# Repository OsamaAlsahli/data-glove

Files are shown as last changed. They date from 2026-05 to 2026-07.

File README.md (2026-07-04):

# Data Glove

Low-cost, high-accuracy data glove with real-time hand motion tracking and
fingertip force sensing.

Final Year Project — **Osama Alsahli**, BEng Electronic Engineering, University
of York, 2026.

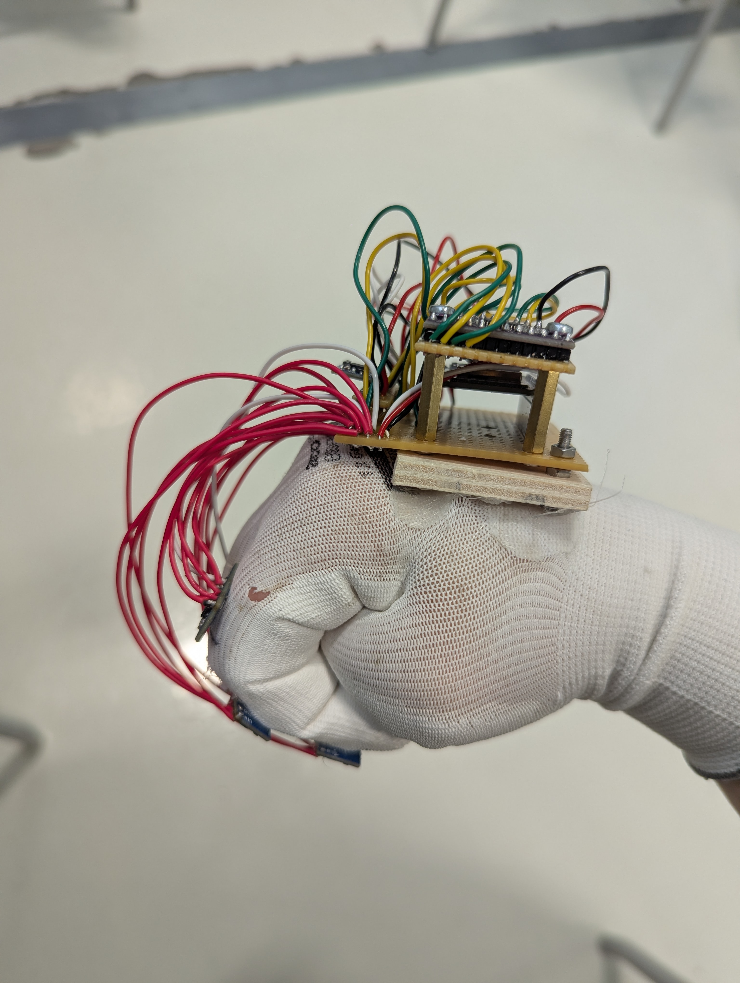
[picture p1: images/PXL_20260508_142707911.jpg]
Data glove prototype with fingertip STOF sensor and IMU wiring


## What this is

A wearable glove that captures finger and hand orientation using sixteen
BNO055 9-axis IMUs (one per finger phalanx plus one on the dorsum), with
soft optical tactile sensors (STOF) at the fingertips for contact force.
Quaternion data is streamed from an ESP32 over USB serial to a Python
bridge, which serves it to the FSGlove visualisation framework via gRPC.

Headline hardware bill of materials: 16× BNO055 IMUs, 2× TCA9548A I2C
multiplexers, one ESP32 dev board, soft Ecoflex 00-30 STOF sensors at the
fingertips. Total cost of purchased electronics ≈ £105.

For the full report (motivation, lit review, design, evaluation), see the
accompanying BEng final report.

## Repository layout

```
firmware/         ESP32 Arduino sketches (C++)
  adafruit_test/  Single-BNO055 smoke test
  tst/            Single sensor through TCA9548A
  tst2/           TCA9548A I2C scanner
  webserial_3d/   Single sensor for the Adafruit WebSerial 3D viewer
  quat_finger/    4-IMU single-finger demo
  quat/           Full 16-IMU glove firmware
  fsglove-main/   FSGlove visualisation framework (third-party, included
                  for reproducibility - see Licence section)

bridge/           Python serial-to-gRPC bridge
  bridge.py            Full 16-sensor bridge (the one you actually run)
  bridge_finger.py     Incomplete 4-sensor variant, kept for reference
  read_imu.py          Minimal serial quaternion printer
  visualise_imu.py     Live OpenGL "bone" visualiser

images/           Prototype photos, kinematic model, Gantt chart
schematics/       PCB / schematic designs (KiCad) for STOF and main board
```

## How to flash the firmware

1. Open `firmware/quat/quat.ino` in the Arduino IDE.
2. Install the **Adafruit BNO055** and **Adafruit Unified Sensor** libraries
   from the Library Manager.
3. Select the ESP32 board, the matching USB serial port, and upload.

The single-sensor bring-up sketches (`adafruit_test`, `tst`, `tst2`,
`webserial_3d`) are useful for verifying hardware before flashing the full
build.

## How to run the bridge

```bash
cd bridge
pip install pyserial grpcio
# Generate imu_packet_pb2.py / imu_packet_pb2_grpc.py from the FSGlove proto
# (imu_packet.proto lives inside firmware/fsglove-main).
python bridge.py
```

The bridge listens on `localhost:18890`; start FSGlove afterwards and it
will subscribe to the stream.

If you want to drive the visualiser without hardware, swap the
`target=read_serial` line in `bridge.py`'s `main()` for
`target=generate_fake_serial`.

## Licence

The code I wrote (everything under `firmware/` except `fsglove-main/`, and
everything under `bridge/`) is released for academic and personal use.

`firmware/fsglove-main/` is included for reproducibility only and is the
work of its original authors — see its own README and licence inside that
folder or (<https://github.com/davidliyutong/fsglove>). The SMPLH model weights (`SMPLH_male.pkl`, `SMPLH_female.pkl`)
required by FSGlove are **not** included in this repo. To obtain them and
get FSGlove running, follow the setup instructions in the upstream FSGlove
repository (<https://github.com/davidliyutong/fsglove>); the project page
is at <https://sites.google.com/view/fsglove/>.

## Known limitations

- **Single multiplexer firmware.** `firmware/quat/quat.ino` was written
  assuming one 16 channel multiplexer, but the final hardware splits the
  16 IMUs across two TCA9548As (each with 8 channels). Reading sensors 8 to 15
  therefore needs a second multiplexer select layer that this build does
  not yet implement. The limitation is flagged inline with a `NOTE:` comment.
  The single finger and 8 sensor paths are fully working.
- `bridge/bridge_finger.py` is an unfinished early version of the bridge,
  kept for historical reference. The working bridge is `bridge/bridge.py`.

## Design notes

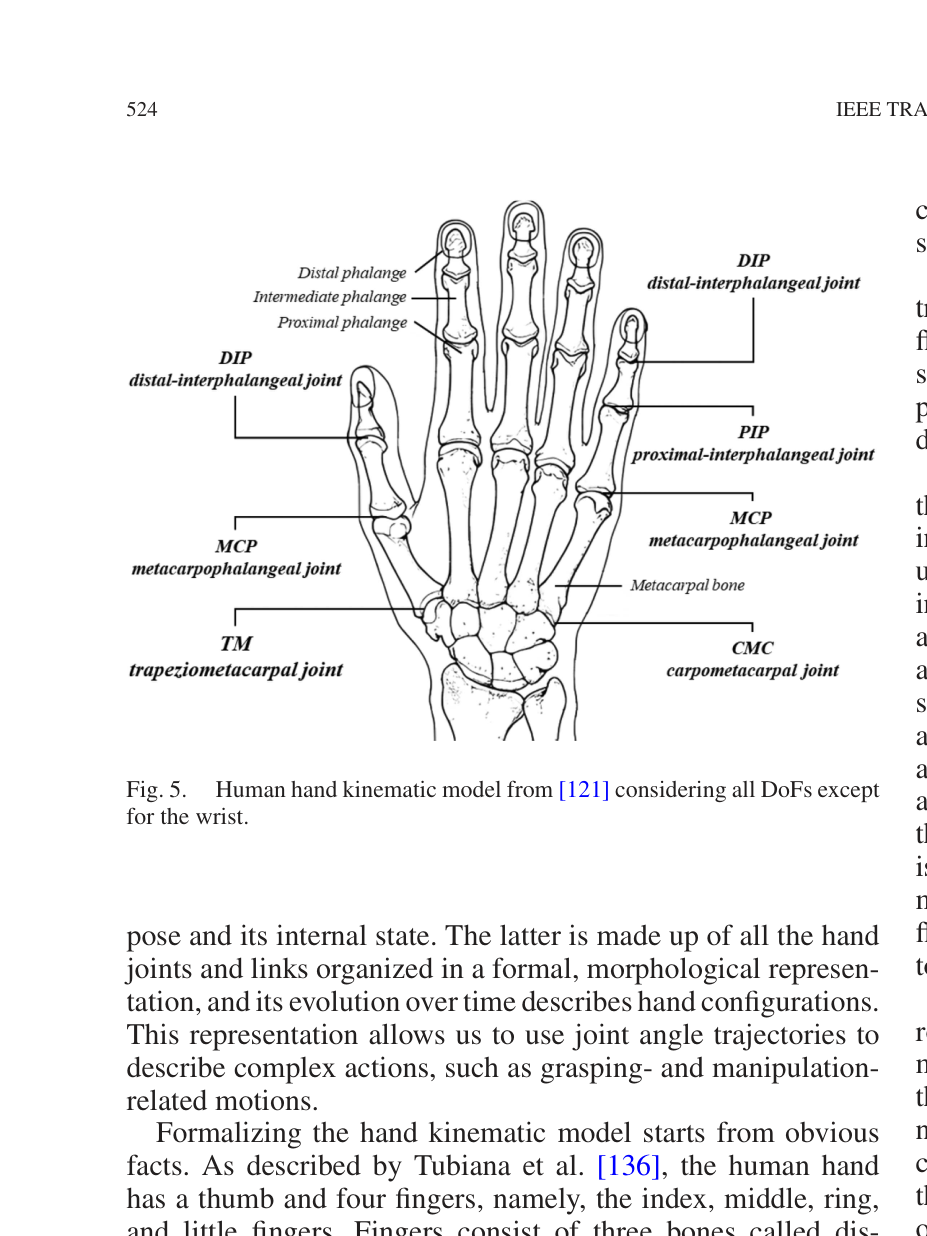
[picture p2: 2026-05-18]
images/hand_kinematic_model.png

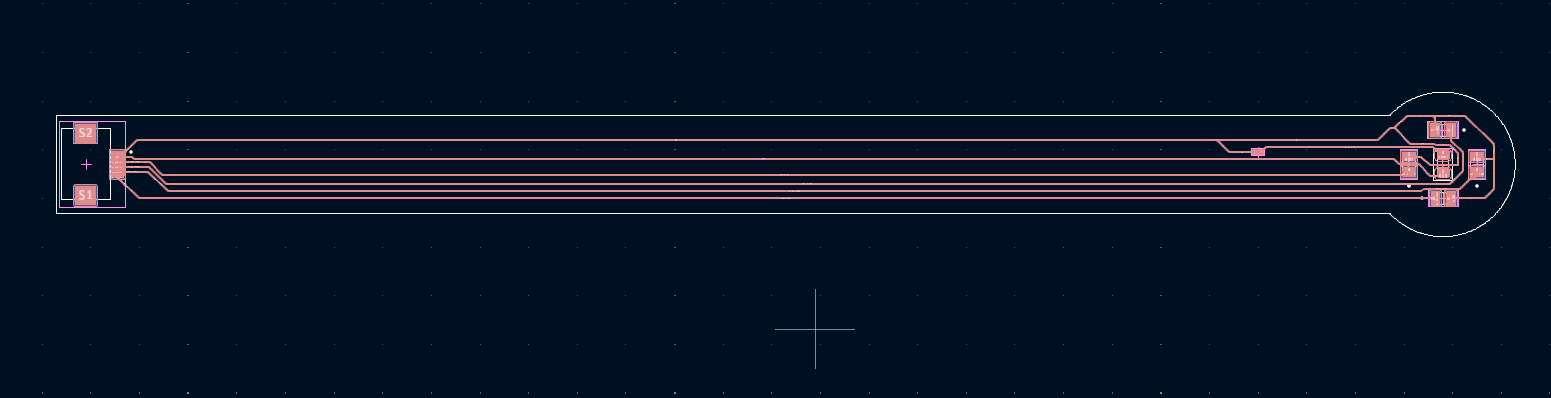
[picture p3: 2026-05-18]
images/Screenshot from 2026-05-17 22-48-20.png

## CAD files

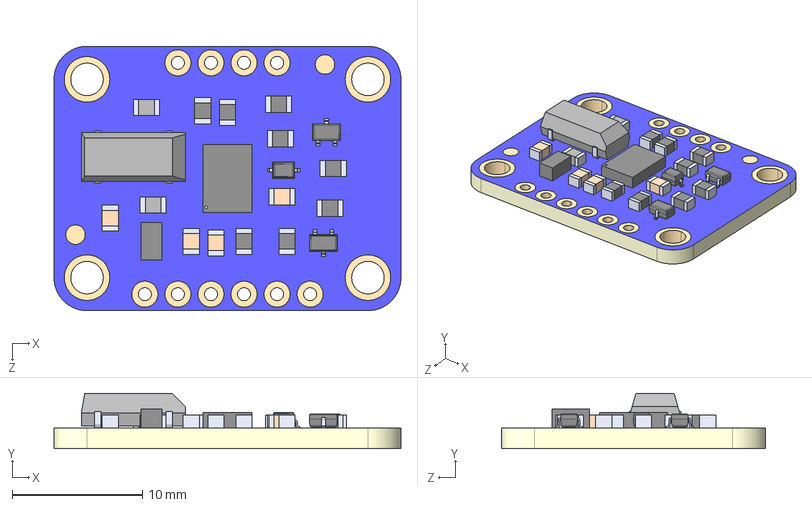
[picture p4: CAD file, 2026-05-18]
schematics/components/bno055/2472.step
26.7 x 4.23 x 20.3 mm
BNO055_BNO055
BSS138_BSS138 x 2
1N4148_1N4148
32.768kHz_32.768kHz

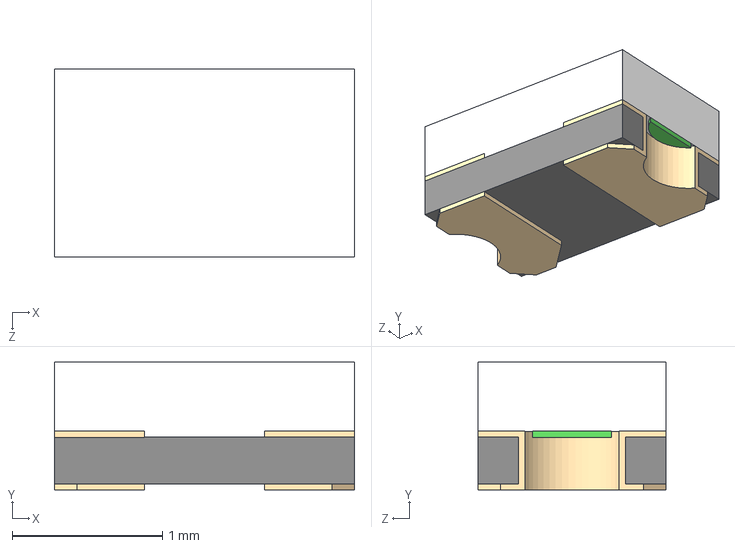
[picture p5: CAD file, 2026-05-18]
schematics/components/TEMD7000X01/TEMD7000X01.step
2.00 x 0.85 x 1.25 mm

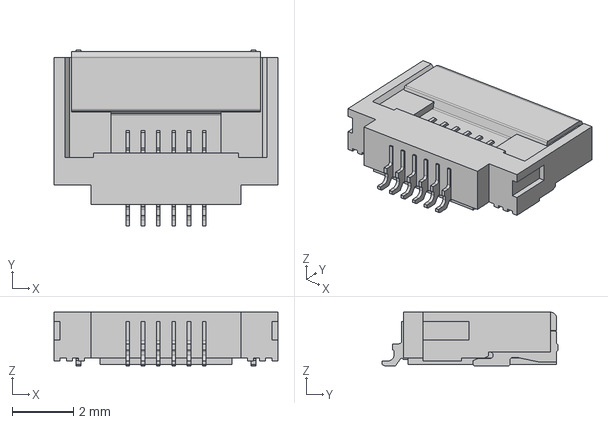
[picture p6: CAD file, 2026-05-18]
schematics/components/TF31-6S-0.5SH_800_/TF31-6S-0.5SH_800_.step
7.30 x 5.75 x 1.75 mm

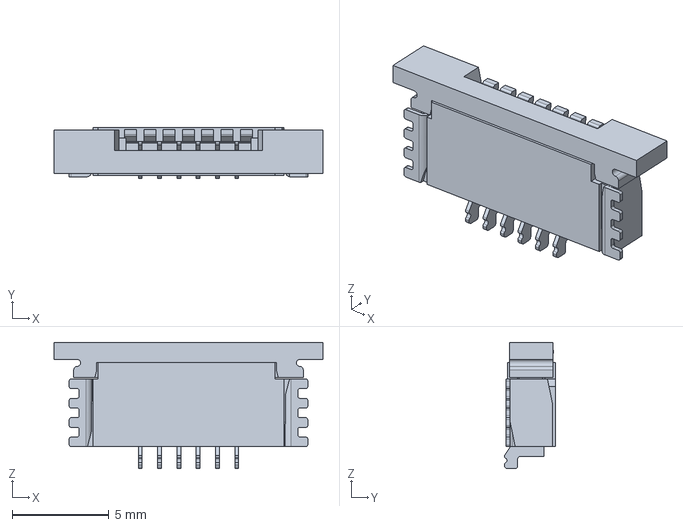
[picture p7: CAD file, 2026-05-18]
schematics/components/84953-6/84953-6.step
13.9 x 2.66 x 6.55 mm

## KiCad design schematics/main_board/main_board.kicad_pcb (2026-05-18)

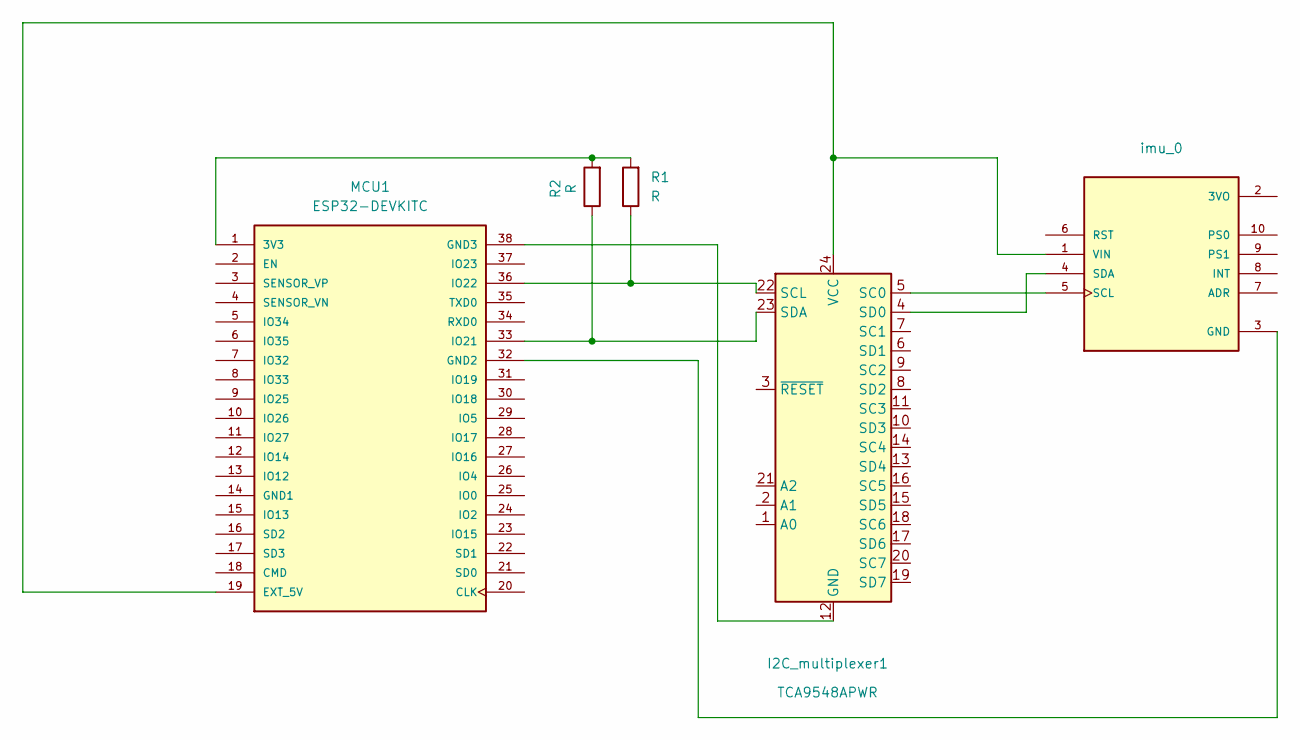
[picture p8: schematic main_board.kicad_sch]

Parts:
I2C_multiplexer1: TCA9548APWR; TSSOP-24_4.4x7.8mm_P0.65mm
MCU1: ESP32-DEVKITC; PARTREV N/A
R1, R2: R; R_0603_1608Metric
imu_0: MODULE_2472; PARTREV N/A

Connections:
unnamed: I2C_multiplexer1.12 (GND), MCU1.38 (GND3)
unnamed: I2C_multiplexer1.5 (SC0), imu_0.5 (SCL)
unnamed: I2C_multiplexer1.22 (SCL), MCU1.36 (IO22), R1.1
unnamed: I2C_multiplexer1.4 (SD0), imu_0.4 (SDA)
unnamed: I2C_multiplexer1.23 (SDA), MCU1.33 (IO21), R2.1
unnamed: I2C_multiplexer1.24 (VCC), MCU1.19 (EXT_5V), imu_0.1 (VIN)
unnamed: MCU1.1 (3V3), R1.2, R2.2
unnamed: MCU1.32 (GND2), imu_0.3 (GND)

Board: 2 copper layers, 5 parts (0 on the bottom side), 8 nets, no tracks yet.

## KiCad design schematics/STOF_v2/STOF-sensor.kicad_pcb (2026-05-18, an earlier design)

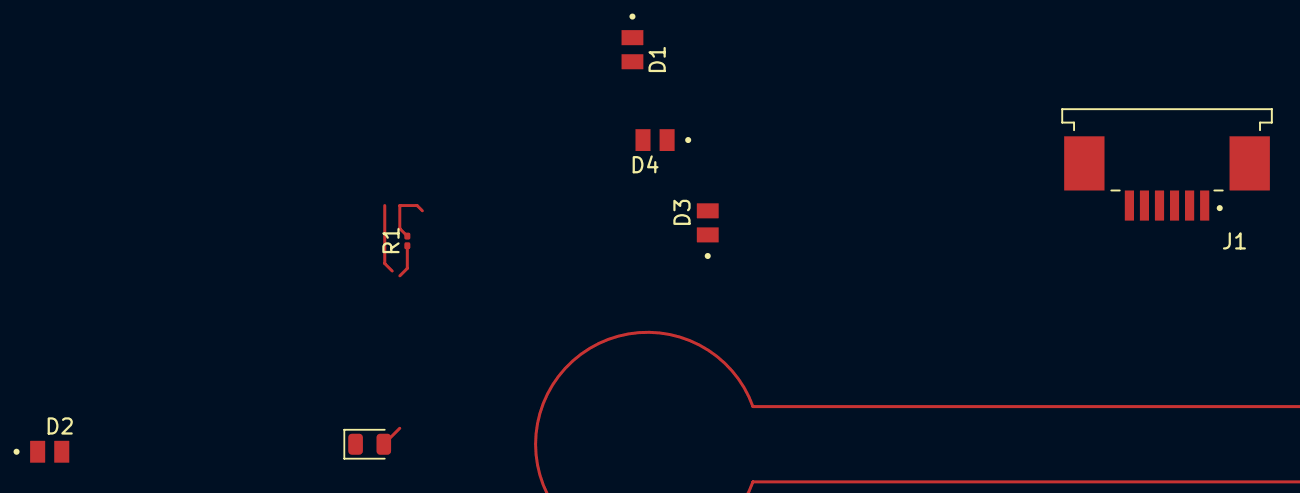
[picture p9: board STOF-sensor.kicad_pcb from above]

Board: 2 copper layers, 7 parts (0 on the bottom side), 8 nets.

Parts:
D1, D2, D3, D4: TEMD7000X01; XDCR_TEMD7000X01
J1: 84953-6; TE_84953-6
LED1: LED; LED_0805_2012Metric
R1: 100; R_0201_0603Metric

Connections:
+5V: D1.C, D2.C, D3.C, D4.C, J1.1, R1.2
GND: J1.2, LED1.1 (K)
unnamed: D1.A, J1.3
unnamed: D2.A, J1.4
unnamed: D3.A, J1.5
unnamed: D4.A, J1.6
unnamed: J1.S1 (SHIELD), J1.S2 (SHIELD)
unnamed: LED1.2 (A), R1.1

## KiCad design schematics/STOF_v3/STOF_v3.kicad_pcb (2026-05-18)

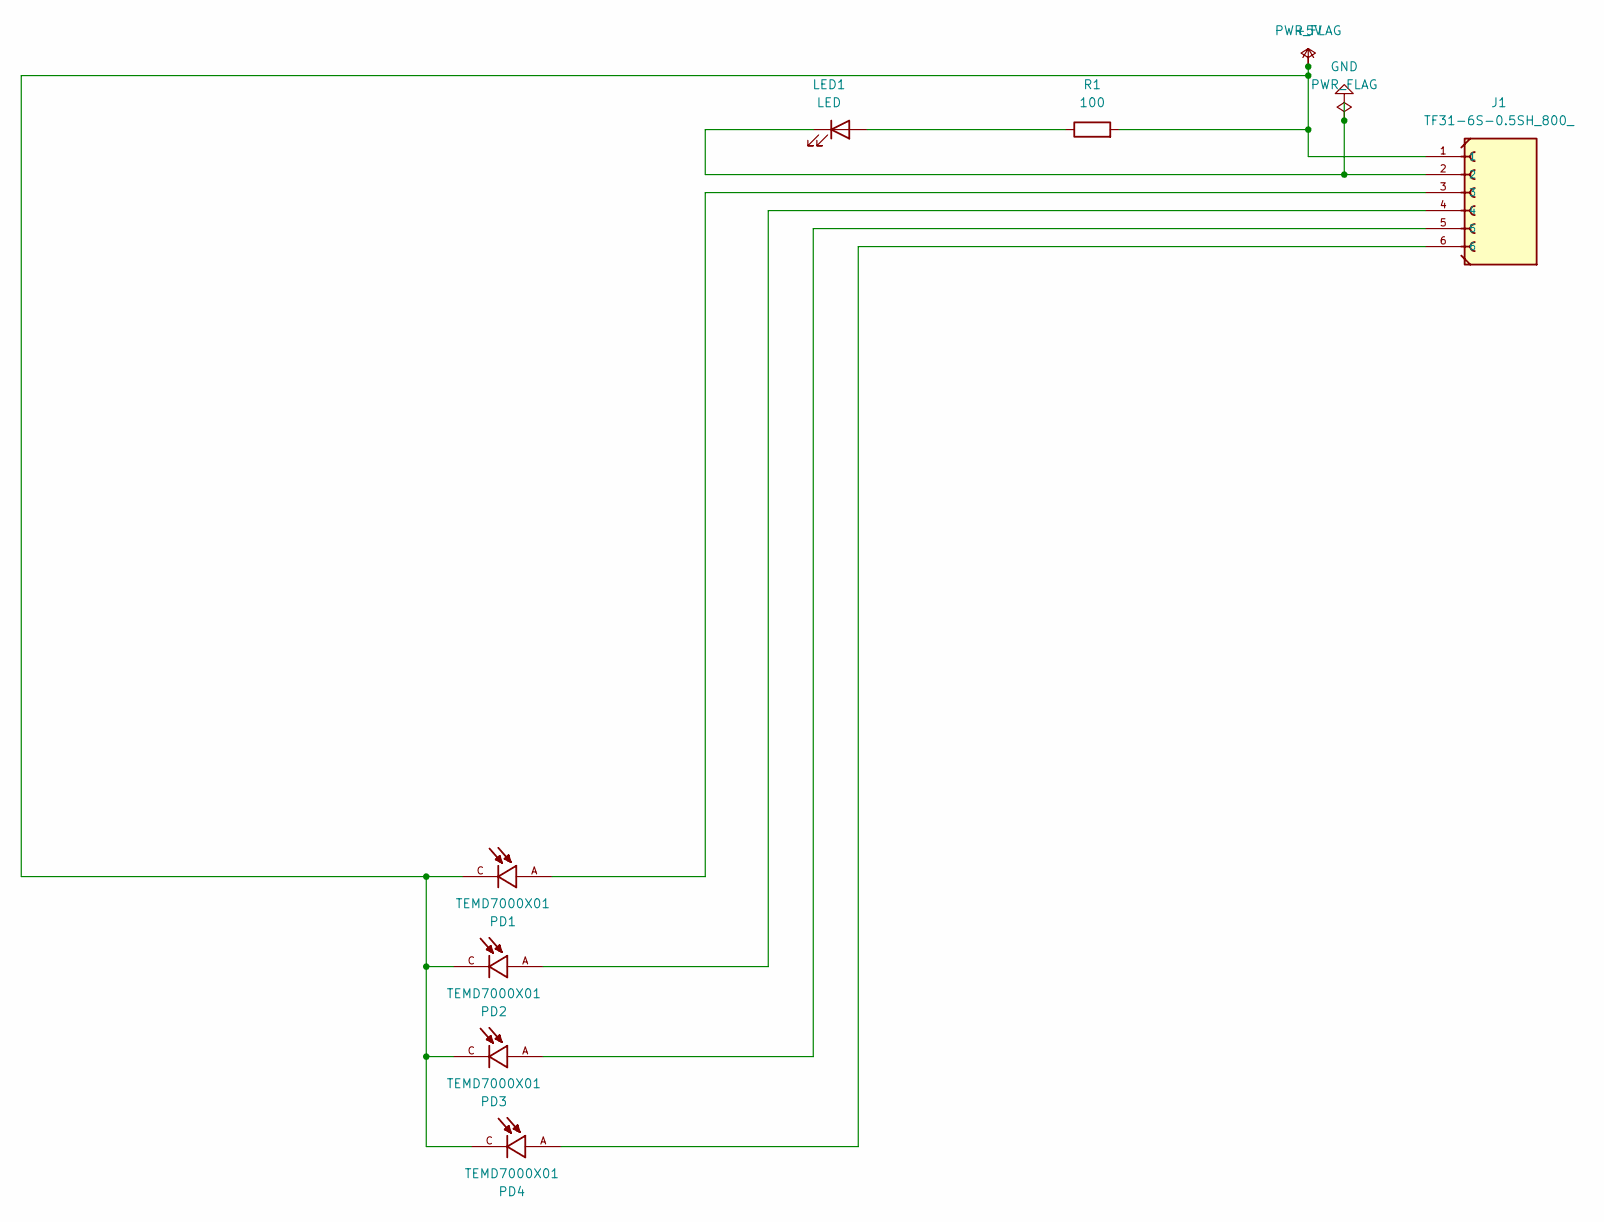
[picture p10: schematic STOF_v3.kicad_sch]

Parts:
J1: TF31-6S-0.5SH_800_; HRS_TF31-6S-0.5SH_800_
LED1: LED; LED_0805_2012Metric
PD1, PD2, PD3, PD4: TEMD7000X01; XDCR_TEMD7000X01
R1: 100; R_0201_0603Metric

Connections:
+5V: J1.1, PD1.C, PD2.C, PD3.C, PD4.C, R1.2
GND: J1.2, LED1.1 (K)
unnamed: J1.3, PD1.A
unnamed: J1.4, PD2.A
unnamed: J1.5, PD3.A
unnamed: J1.6, PD4.A
unnamed: LED1.2 (A), R1.1

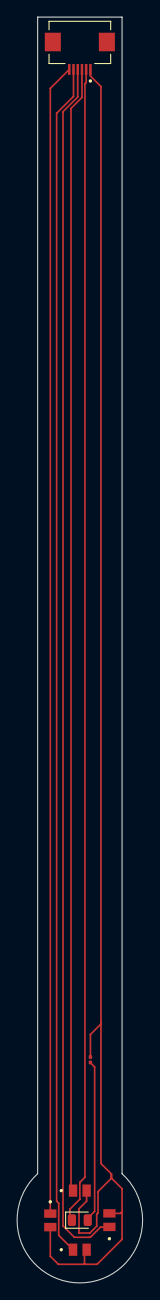
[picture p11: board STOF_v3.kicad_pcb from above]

Board: 2 copper layers, 14.9 x 149.9 mm, 7 parts (0 on the bottom side), 7 nets.

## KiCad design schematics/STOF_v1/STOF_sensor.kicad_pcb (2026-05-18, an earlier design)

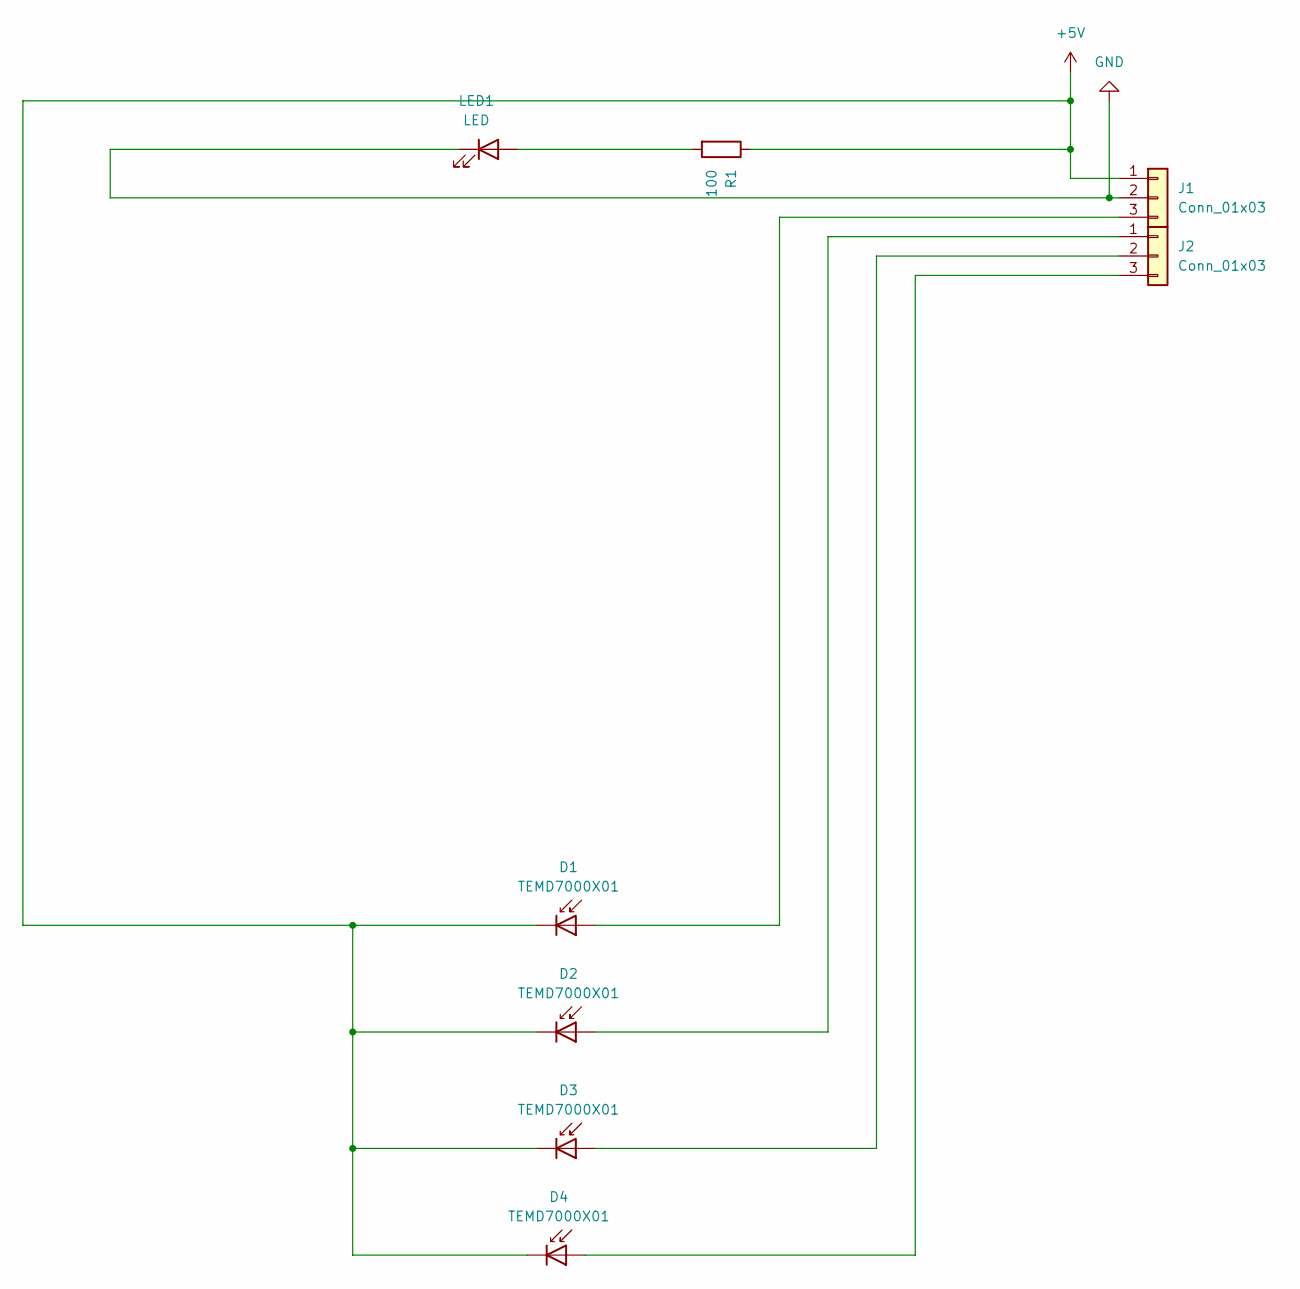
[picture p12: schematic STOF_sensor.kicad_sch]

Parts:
D1, D2, D3, D4: TEMD7000X01; LED_0805_2012Metric
J1, J2: Conn_01x03; SolderWire-0.1sqmm_1x03_P3.6mm_D0.4mm_OD1mm
LED1: LED; LED_0805_2012Metric
R1: 100; R_0603_1608Metric

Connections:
+5V: D1.1 (K), D2.1 (K), D3.1 (K), D4.1 (K), J1.1, R1.1
GND: J1.2, LED1.1 (K)
unnamed: D1.2 (A), J1.3
unnamed: D2.2 (A), J2.1
unnamed: D3.2 (A), J2.2
unnamed: D4.2 (A), J2.3
unnamed: LED1.2 (A), R1.2

Board: 2 copper layers, 8 parts (0 on the bottom side), 7 nets, no tracks yet.

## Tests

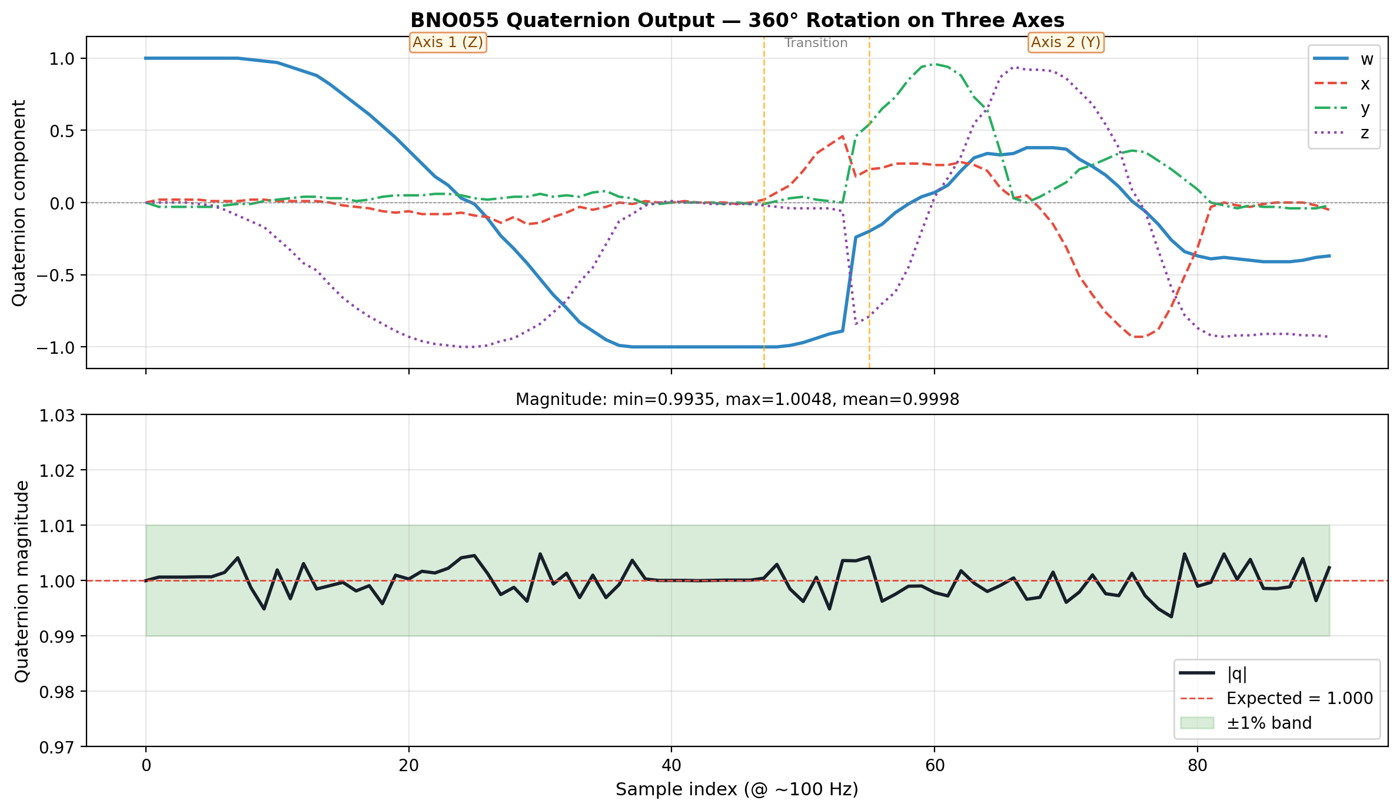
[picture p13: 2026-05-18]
images/quaternion_rotation_test.png

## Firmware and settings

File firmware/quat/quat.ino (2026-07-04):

// quat.ino - Full 16-IMU data glove firmware for ESP32
//
// Reads orientation quaternions from sixteen BNO055 IMUs distributed across
// two TCA9548A I2C multiplexers and streams them over USB serial as a single
// pipe-separated line per sample.
//
// Wiring assumptions:
//   - ESP32 default I2C pins (SDA = 21, SCL = 22)
//   - TCA9548A multiplexer at I2C address 0x70
//   - All BNO055 modules have their ADR pin tied to 3.3 V, giving address
//     0x29 (the AliExpress boards used here defaulted to 0x28, which clashed
//     with the multiplexer in some test setups, so 0x29 was forced)
//
// Output format (one line per sample, terminated with \n):
//   w,x,y,z|w,x,y,z|...|w,x,y,z       (16 quaternions, 15 separators)

#include <Wire.h>
#include <Adafruit_Sensor.h>
#include <Adafruit_BNO055.h>
#include <utility/imumaths.h>

#define TCAADDR 0X70   // I2C address of the TCA9548A multiplexer

// One Adafruit_BNO055 object per sensor. The first argument is a local id
// used by the library, the second is the I2C address as seen through the mux.
Adafruit_BNO055 imus[16] = {
  Adafruit_BNO055(0,0x29),
  Adafruit_BNO055(1,0x29),
  Adafruit_BNO055(2,0x29),
  Adafruit_BNO055(3,0x29),
  Adafruit_BNO055(4,0x29),
  Adafruit_BNO055(5,0x29),
  Adafruit_BNO055(6,0x29),
  Adafruit_BNO055(7,0x29),
  Adafruit_BNO055(8,0x29),
  Adafruit_BNO055(9,0x29),
  Adafruit_BNO055(10,0x29),
  Adafruit_BNO055(11,0x29),
  Adafruit_BNO055(12,0x29),
  Adafruit_BNO055(13,0x29),
  Adafruit_BNO055(14,0x29),
  Adafruit_BNO055(15,0x29)
};

// Activate channel `i` on the TCA9548A so that subsequent I2C traffic is
// routed only to the device on that channel. Writing a one-hot byte selects
// the channel; writing 0 disables all channels.
void tcaselect(uint8_t i) {
  if (i > 7) return;
  Wire.beginTransmission(TCAADDR);
  Wire.write(1 << i);
  Wire.endTransmission();
}

// Select the multiplexer channel, query the BNO055, and print a comma-
// separated quaternion (no trailing separator so the caller controls layout).
void read_imu_quat(int imu_id, int mp_addr){
  tcaselect(mp_addr);
  imu::Quaternion quat = imus[imu_id].getQuat();
  Serial.print(quat.w());
  Serial.print(",");
  Serial.print(quat.x());
  Serial.print(",");
  Serial.print(quat.y());
  Serial.print(",");
  Serial.print(quat.z());
}

// Read all sixteen sensors and emit one full sample.
// NOTE: this firmware was written assuming a single 16-channel mux; in the
// final hardware the IMUs are split across two TCA9548As, so a second
// multiplexer-select layer is required for sensors 8-15 in a follow-up build.
void read_all_imu(){
  read_imu_quat(0, 0);
  Serial.print("|");
  read_imu_quat(1, 1);
  Serial.print("|");
  read_imu_quat(2, 2);
  Serial.print("|");
  read_imu_quat(3, 3);
  Serial.print("|");
  read_imu_quat(4, 4);
  Serial.print("|");
  read_imu_quat(5, 5);
  Serial.print("|");
  read_imu_quat(6, 6);
  Serial.print("|");
  read_imu_quat(7, 7);
  Serial.print("|");
  read_imu_quat(8, 8);
  Serial.print("|");
  read_imu_quat(9, 9);
  Serial.print("|");
  read_imu_quat(10, 10);
  Serial.print("|");
  read_imu_quat(11, 11);
  Serial.print("|");
  read_imu_quat(12, 12);
  Serial.print("|");
  read_imu_quat(13, 13);
  Serial.print("|");
  read_imu_quat(14, 14);
  Serial.print("|");
  read_imu_quat(15, 15);  // NOTE: sensors 8-15 need a second TCA9548A select layer (see file header) - not yet implemented.
}

void setup(void){
  Serial.begin(115200);
  Wire.begin();
  // Walk every channel, bring up the BNO055 on that channel, and enable the
  // external 32 kHz crystal for better orientation stability.
  for(int i=0; i<16; i++){
    tcaselect(i);
    if(!imus[i].begin()){
      Serial.print("Ooops, no BNO055 detected ... Check your wiring or I2C ADDR!");
      while(1);   // halt - missing IMU means the rest of the stream would be invalid
    }
    imus[i].setExtCrystalUse(true);
  }
}

void loop(void){
  read_all_imu();
  Serial.println();
  delay(10);   // ~100 Hz update target (actual rate limited by I2C + mux switching)
}

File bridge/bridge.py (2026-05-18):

"""bridge.py - Serial-to-gRPC bridge between the ESP32 firmware and FSGlove.

The ESP32 streams sixteen quaternions per sample over USB serial in the form:
    w,x,y,z|w,x,y,z|...|w,x,y,z\n

FSGlove expects to consume IMU samples over gRPC on localhost:18890 using the
IMUPacketService schema defined in imu_packet.proto. This script:

    1. Opens /dev/ttyUSB0 at 115200 baud.
    2. Continuously reads frames from the ESP32 in a background thread and
       caches the latest quaternion for each of the 16 sensors.
    3. Runs a gRPC server that streams those cached quaternions to FSGlove
       whenever it subscribes via GetPacketArrayStream.

A simulated-data path (generate_fake_serial) is included for working on the
visualisation pipeline when the physical hardware is not connected.
"""

import serial
import threading
import time
import math
from concurrent import futures

import grpc
import imu_packet_pb2
import imu_packet_pb2_grpc


# Serial port and shared state. ttyUSB0 is the default ESP32 enumeration on
# Linux; change this if your board appears as a different /dev node.
ser = serial.Serial('/dev/ttyUSB0', 115200)

# Cache of the most recent quaternion for each sensor. Initialised to the
# identity rotation (no rotation) so a subscriber that connects before the
# first serial frame arrives still gets a valid response.
quats = [[0.0, 0.0, 0.0, 1.0]] * 16

# Guards `quats` against concurrent read/write between the serial reader
# thread and the gRPC stream handler.
lock = threading.Lock()


def generate_fake_serial():
    """Stand-in for read_serial used when no hardware is connected.

    Produces a smoothly varying quaternion for each sensor so the downstream
    visualisation can be exercised without an ESP32 on the bench.
    """
    t = 0
    while True:
        with lock:
            for i in range(16):
                # Each sensor gets a different phase so they animate
                # independently rather than all moving in lockstep.
                angle = math.sin(t * 0.5 + i * 0.3) * 0.5
                quats[i] = [math.cos(angle/2), math.sin(angle/2), 0.0, 0.0]
        t += 0.01
        time.sleep(0.01)


def read_serial():
    """Read one line per loop from the ESP32 and update the quaternion cache.

    Each line is expected to contain up to 16 quaternions separated by '|',
    with each quaternion as four comma-separated floats (w,x,y,z). Partial
    frames are tolerated - only the entries that actually parse correctly
    are written into the cache.
    """
    while True:
        try:
            line = ser.readline().decode('utf-8').strip()
            if not line:
                continue

            # Split by the pipe character
            sensor_quat = line.split('|')

            with lock:
                # Use len(sensor_quat) so we never go "out of range"
                for i in range(len(sensor_quat)):
                    # Safety: don't exceed the 16 slots we allocated for 'quats'
                    if i >= 16:
                        break

                    values = sensor_quat[i].split(',')
                    if i==0:
                        # Sensor 0 is the wrist (dorsum) - log it for sanity
                        # checking while the bridge is running.
                        quats[0] = [float(v) for v in values]
                        print(f"Wrist Quat: {quats[0]}")
                    if len(values) == 4:
                        quats[i] = [float(v) for v in values]

        except Exception as e:
            # A malformed frame should not kill the bridge; log and continue.
            print(f"Serial Error: {e}")

class IMUBridge(imu_packet_pb2_grpc.IMUPacketServiceServicer):
    """gRPC servicer implementing the slice of IMUPacketService that FSGlove
    actually calls. The other methods are stubs that return success/empty
    responses so FSGlove's startup probes don't error out."""

    def GetPacketArrayStream(self, request, context):
        """Stream the latest cached quaternions to FSGlove until it
        disconnects. Yields one IMUPacketArrayStreamResponse per ~10 ms."""
        while context.is_active():
            # Snapshot the shared cache under the lock so the gRPC payload
            # is consistent even if the serial thread updates mid-iteration.
            with lock:
                current_quats = list(quats)
            packets = {}
            for i in range(16):
                packets[f"imu_{i}"] = imu_packet_pb2.IMUPacketResponseRaw(
                    id = f"imu_{i}",
                    quat_w=current_quats[i][0],
                    quat_x=current_quats[i][1],
                    quat_y=current_quats[i][2],
                    quat_z=current_quats[i][3]
                )
            synced = imu_packet_pb2.IMUPacketResponseSynced(
                packets=packets,
                sys_ticks=int(time.time() * 1000)
            )
            response = imu_packet_pb2.IMUPacketArrayStreamResponse(
                packets = [synced],
                valid = True
            )
            yield response
            time.sleep(0.01)   # ~100 Hz output cap

    # The remaining methods are required by the proto but unused by the
    # current FSGlove flow - return minimal success responses.
    def SetFIFOStatus(self, request, context):
        return imu_packet_pb2.IMUStatusResponse(status=True)

    def GetFIFOStatus(self, request, context):
        return imu_packet_pb2.IMUStatusResponse(status=True)

    def GetPacketArray(self, request, context):
        return imu_packet_pb2.IMUPacketArrayResponse()

    def ListDev(self, request, context):
        return imu_packet_pb2.IMUInfoResponse()

def main():
    # Start the serial reader as a daemon thread so Ctrl-C exits cleanly.
    # Swap read_serial for generate_fake_serial here to run without hardware.
    serial_thread = threading.Thread(target=read_serial)
    serial_thread.daemon=True
    serial_thread.start()

    # Stand up the gRPC server. Port 18890 matches what FSGlove dials by default.
    server = grpc.server(futures.ThreadPoolExecutor(max_workers=10))
    imu_packet_pb2_grpc.add_IMUPacketServiceServicer_to_server(IMUBridge(), server)
    server.add_insecure_port('[::]:18890')
    server.start()
    server.wait_for_termination()

if __name__ == '__main__':
    print("Server running on port 18890...")
    main()

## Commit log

2026-05-18 Initial commit: BEng final-year project data glove
    Sixteen-IMU data glove with fingertip force sensing.
    Includes ESP32 firmware, Python serial-to-gRPC bridge,
    prototype photos, and PCB / schematic designs.
    [2472.step, 84953-6.step, STOF-sensor.kicad_pcb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]
2026-07-04 Add prototype photo, fix sensor-15 mux channel, clarify firmware limitation
    [quat.ino]
